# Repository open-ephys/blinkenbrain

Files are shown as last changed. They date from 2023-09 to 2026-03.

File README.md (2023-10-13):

# Blinkenbrain
A mouse brain pendant with chaotic tendencies. It implements a variant of the circuit described in

```
Simple Two-Transistor Single-Supply Resistor–Capacitor Chaotic Oscillator
Lars Keuninckx, Guy Van der Sande, and Jan Danckaert
IEEE TRANSACTIONS ON CIRCUITS AND SYSTEMS—II: EXPRESS BRIEFS, VOL. 62, NO. 9, SEPTEMBER 2015
```

and uses its strange dynamics to blink a blinkenlight.

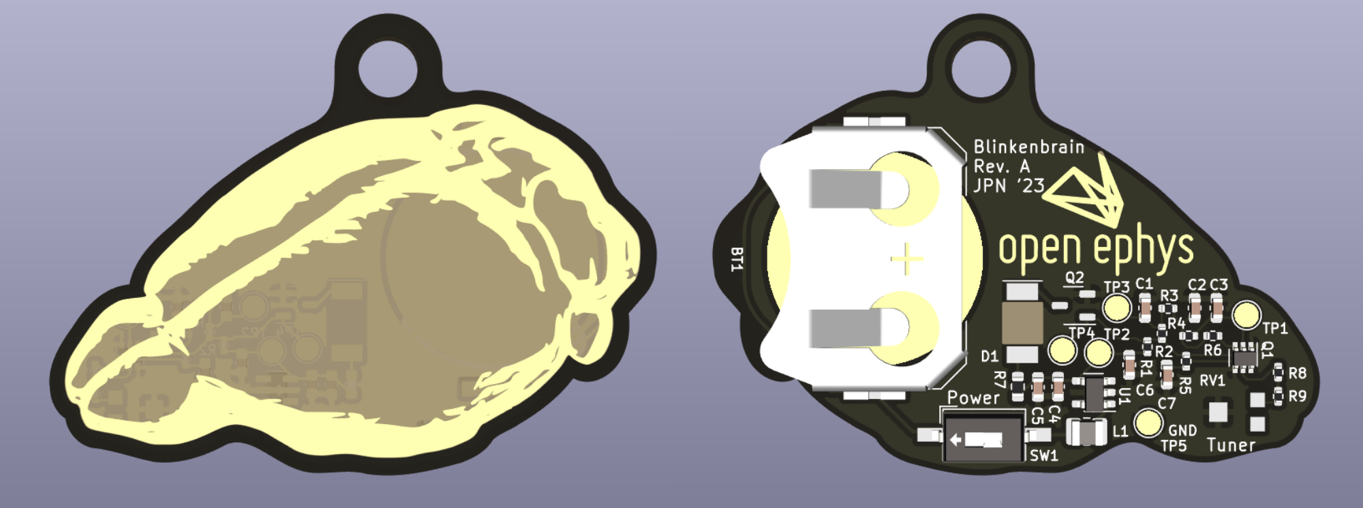
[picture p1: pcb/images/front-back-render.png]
Blinkenbrain rev. A


## How does it blink?

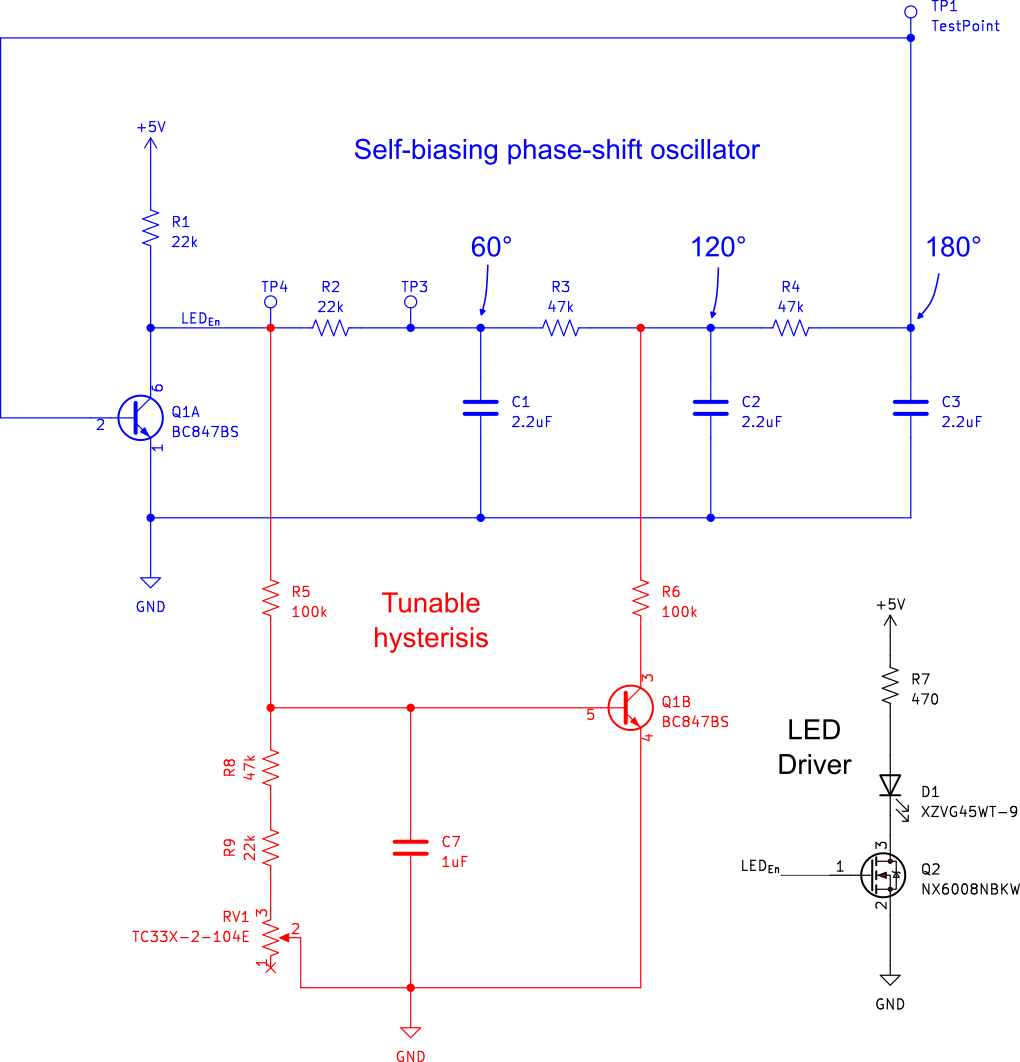
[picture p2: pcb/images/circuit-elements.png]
Chaotic circuit schematic


The circuit consists of a RC phase shift oscillator (blue) combined with what amounts to a tunable Schmitt trigger (red).
The position of the trimpot (RV1) determines if the effect of the Schmitt trigger on the oscillator.

- When the wiper of RV1 is tuned to 0Ω, Q1B does not conduct, and the Schmitt trigger is effectively removed from the circuit
- When the wiper of RV1 is tuned to 100kΩ, Q1B acts as trigger without hysteresis, and therefore conducts in synchrony with the
  RC oscillator.
- When the wiper of RV1 is turned in between these two extremes, a hysteretic path is formed between Q1B's conducting and non-conducting states,
  which results in the emergence of two interacting unstable equilibria and, for some values of RV1, chaotic dynamics.

The gate of an N-channel MOSFET is tied to the collector of Q1A to drive the LED without influencing the
circuit's dynamics. The following image shows V<sub>TP4</sub> vs.V<sub>TP3</sub> when RV1 is tuned to ~70kΩ.

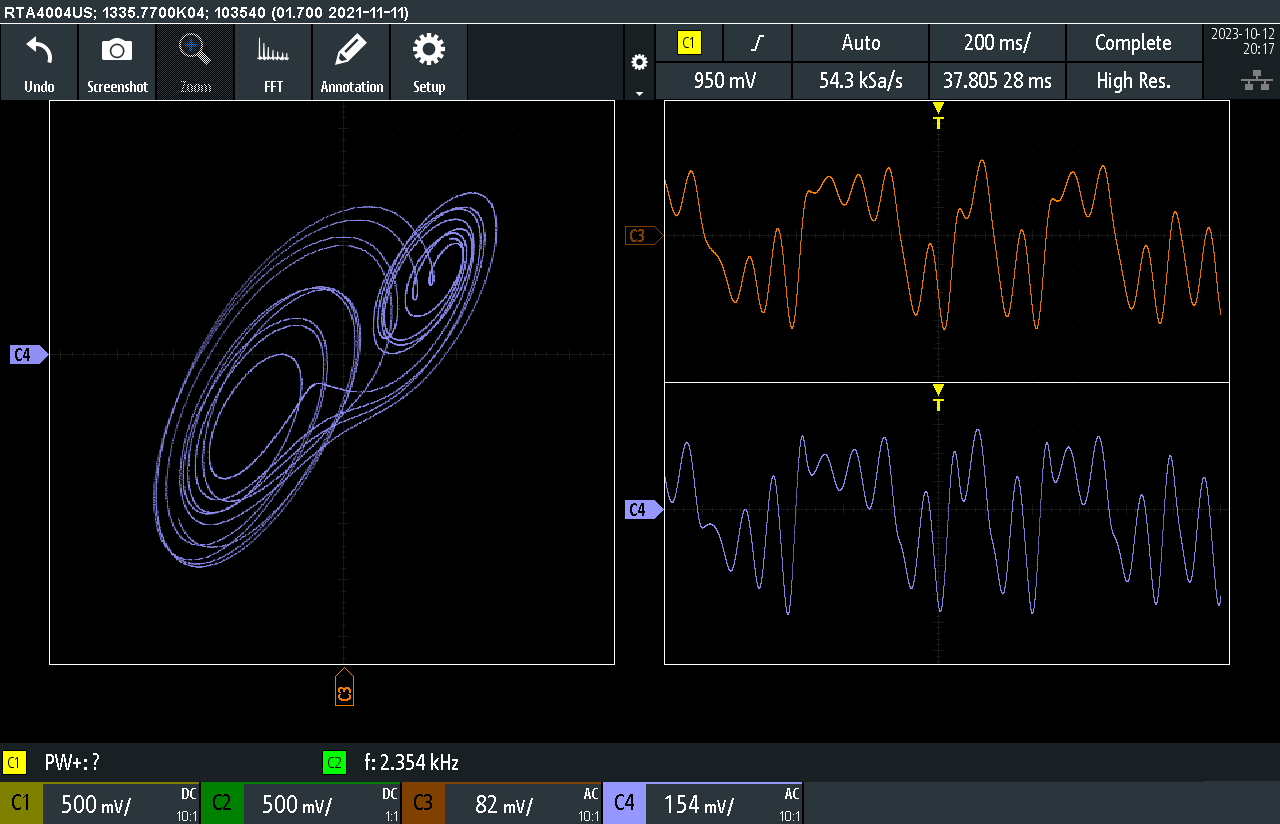
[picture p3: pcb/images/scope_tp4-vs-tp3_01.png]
V(TP4) vs. V(TP3) when RV1 is tuned to ~70kΩ


## License
"No Rights Reserved", CC0

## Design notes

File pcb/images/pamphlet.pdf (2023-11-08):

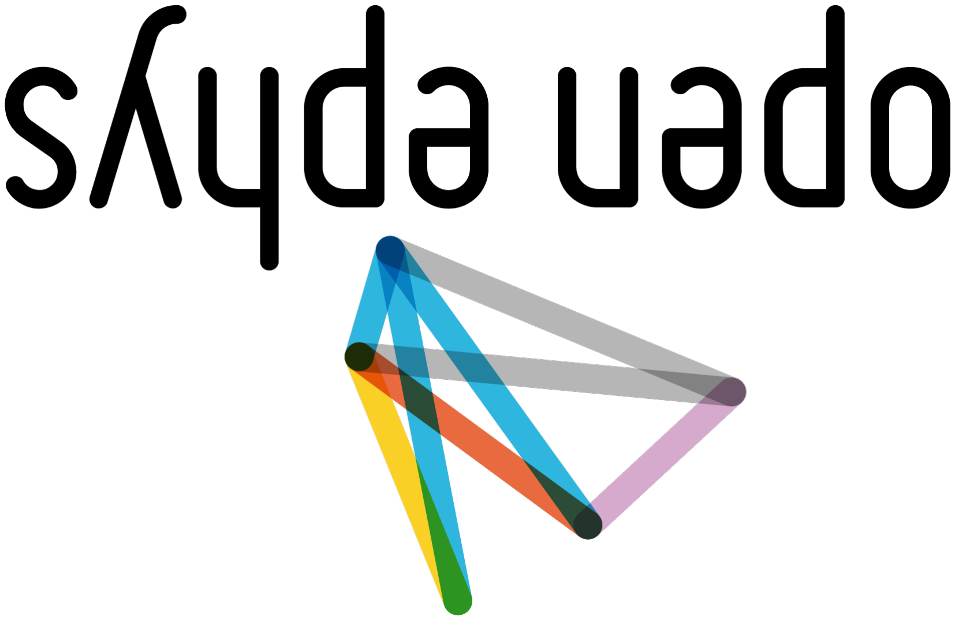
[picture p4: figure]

- When the wiper of RV1 is tuned to 0Ω, Q1B does not conduct, and the Schmitt trigger is effectively removed from the circuit.
- When the wiper of RV1 is tuned to 100kΩ, Q1B acts as trigger without hysteresis, and therefore conducts in synchrony with the RC oscillator.
- When the wiper of RV1 is turned in between these two extremes, a hysteretic path is formed between Q1B's conducting and non-conducting states, which results in the emergence of two interacting unstable equilibria and, for some values of RV1, chaotic dynamics.

The gate of an N-channel MOSFET is tied to the collector of Q1A to drive the LED without influencing the circuit's dynamics. The following image shows VTP4 vs.VTP3 when RV1 is tuned to ~70kΩ.

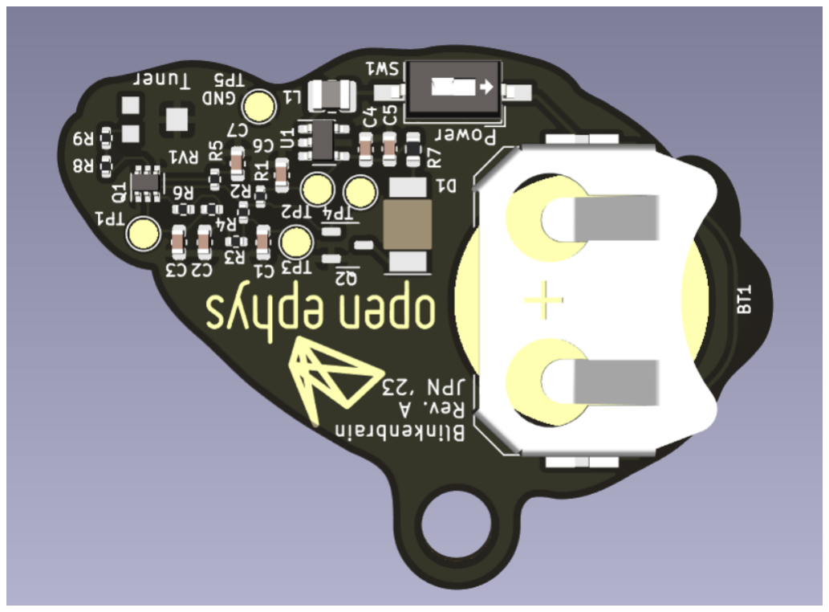
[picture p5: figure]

# How does it blink?

The circuit¹
consists of a RC phase shift oscillator (blue) combined with what amounts to a tunable Schmitt trigger (red). The position of the trimpot (RV1) determines if the effect of the Schmitt trigger on the oscillator.

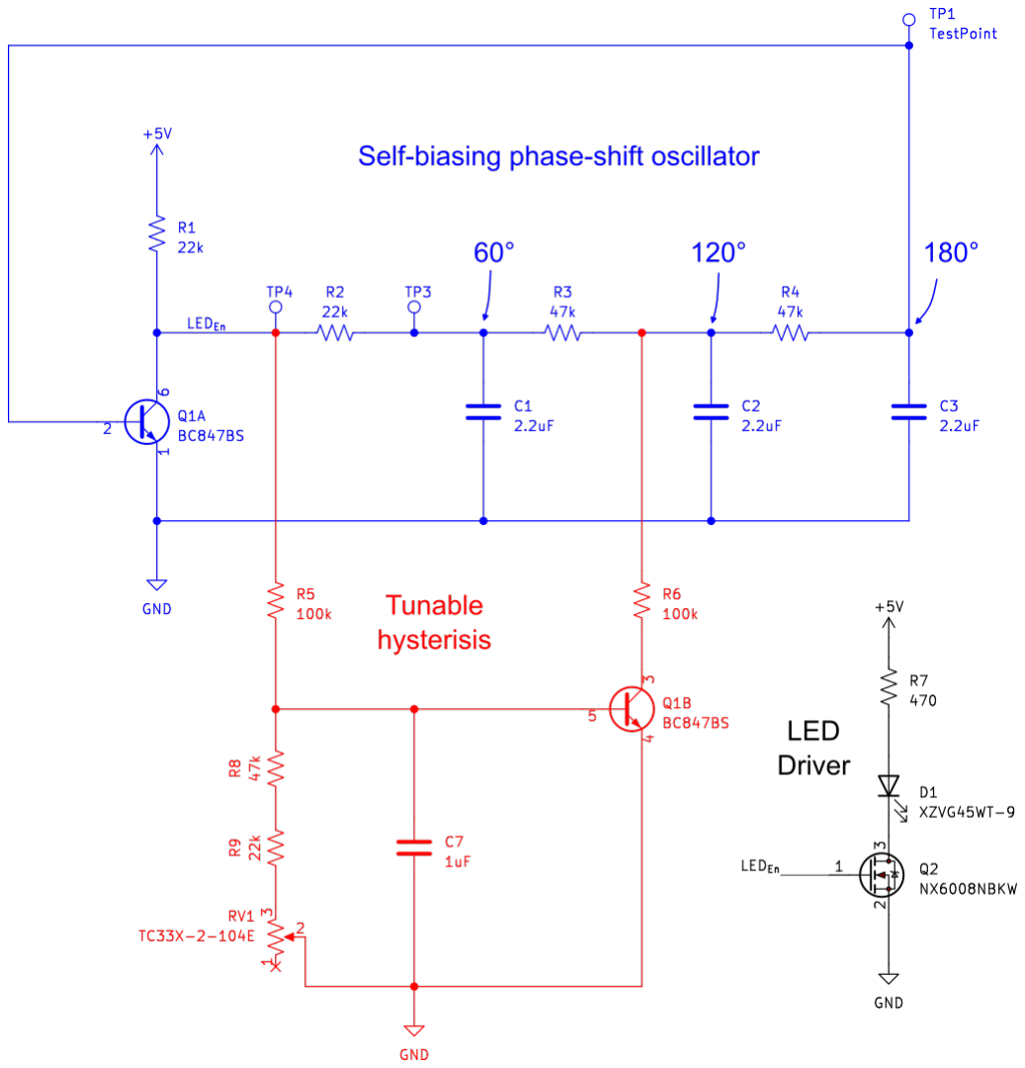
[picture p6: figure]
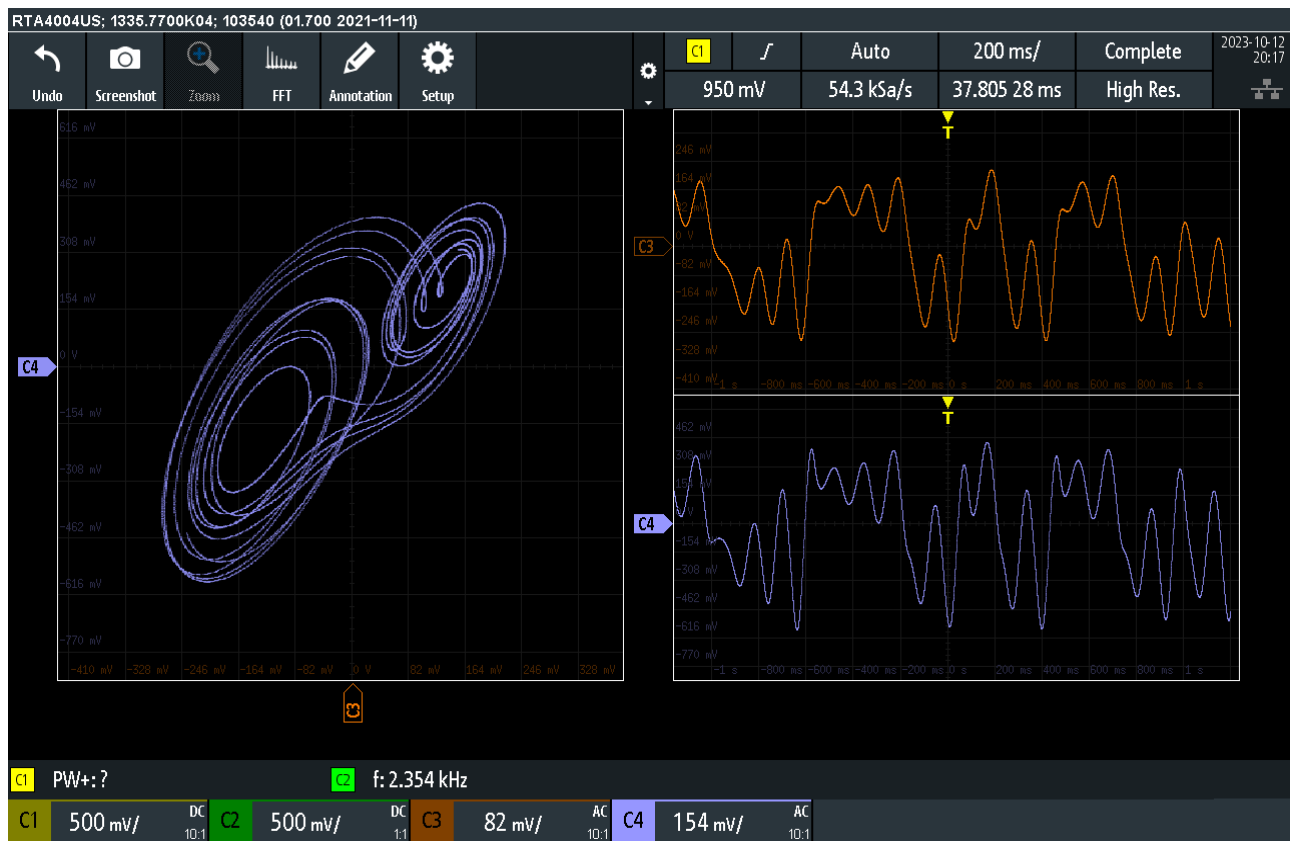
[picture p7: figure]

1. Simple Two-Transistor Single-Supply Resistor–Capacitor Chaotic Oscillator Lars Keuninckx, Guy Van der Sande, and Jan Danckaert IEEE TRANS. ON CIRCUITS AND SYSTEMS II: VOL. 62, NO. 9, 2015

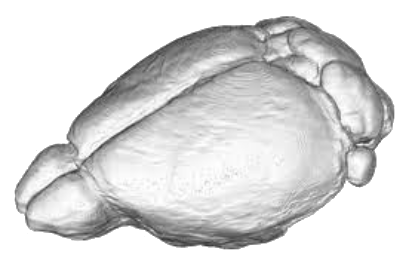
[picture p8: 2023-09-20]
design/brain-image.png

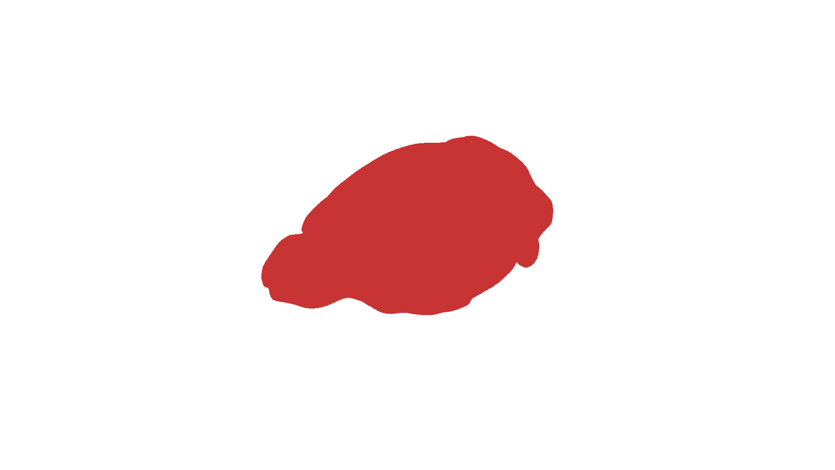
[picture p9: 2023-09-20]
design/brain-mask.png

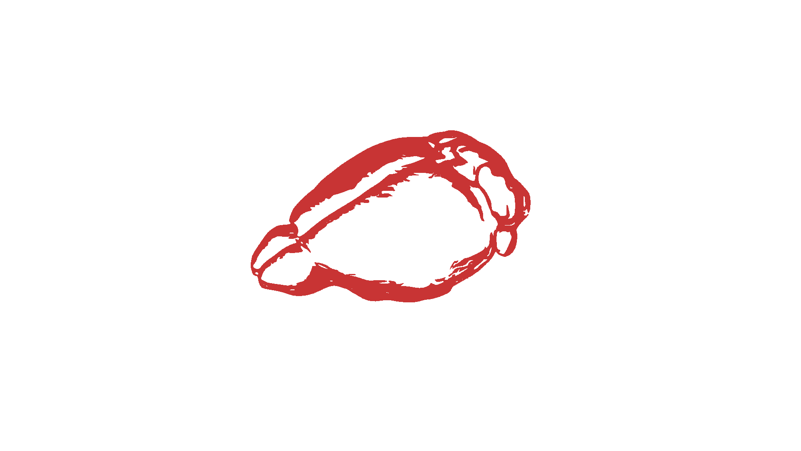
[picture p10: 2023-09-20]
design/brain-copper.png

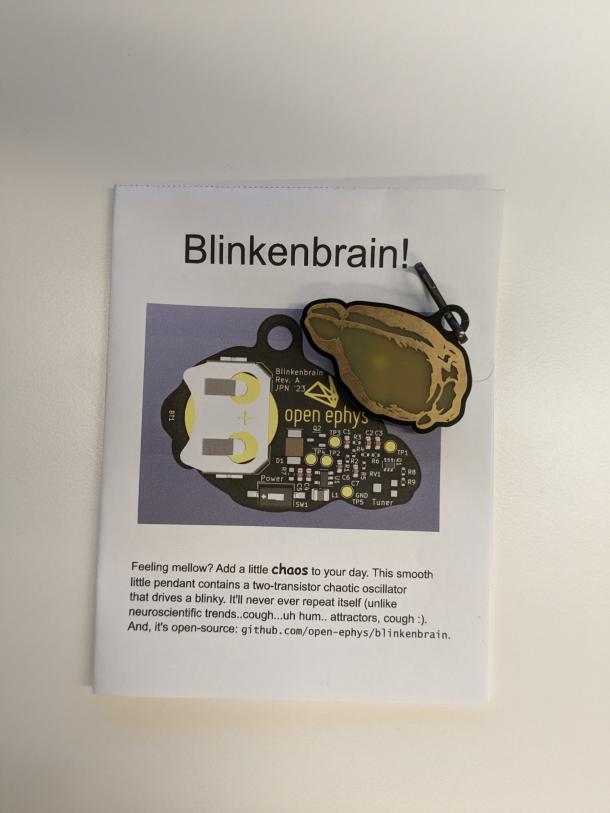
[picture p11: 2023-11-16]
pcb/images/brain-and-datasheet.jpg

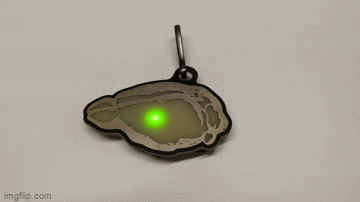
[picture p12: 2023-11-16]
pcb/images/blink.gif

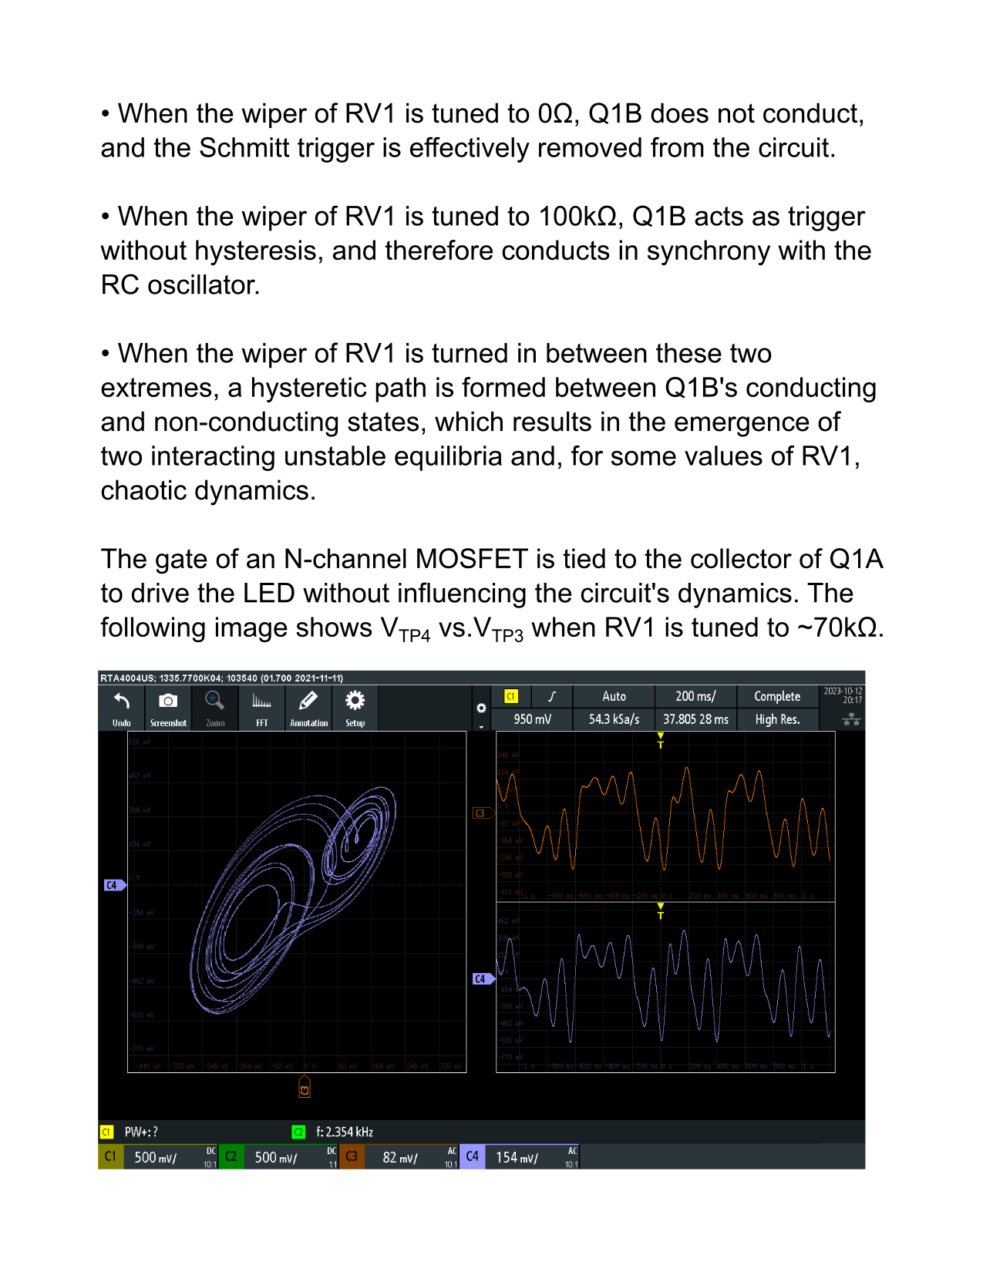
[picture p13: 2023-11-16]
pcb/images/pamphlet-pg3.png

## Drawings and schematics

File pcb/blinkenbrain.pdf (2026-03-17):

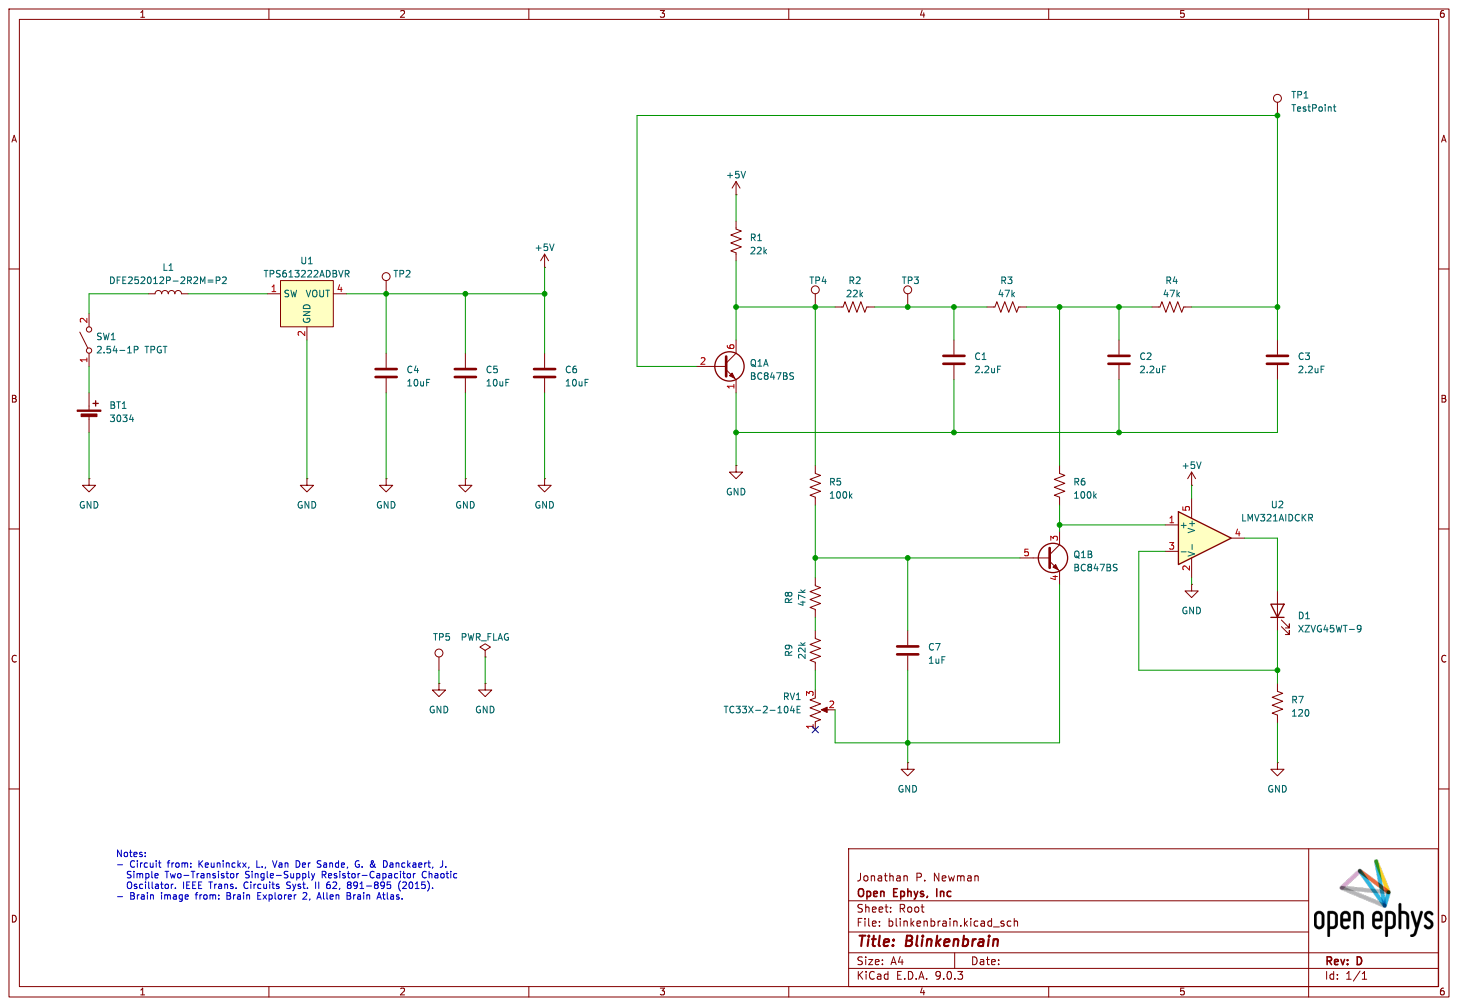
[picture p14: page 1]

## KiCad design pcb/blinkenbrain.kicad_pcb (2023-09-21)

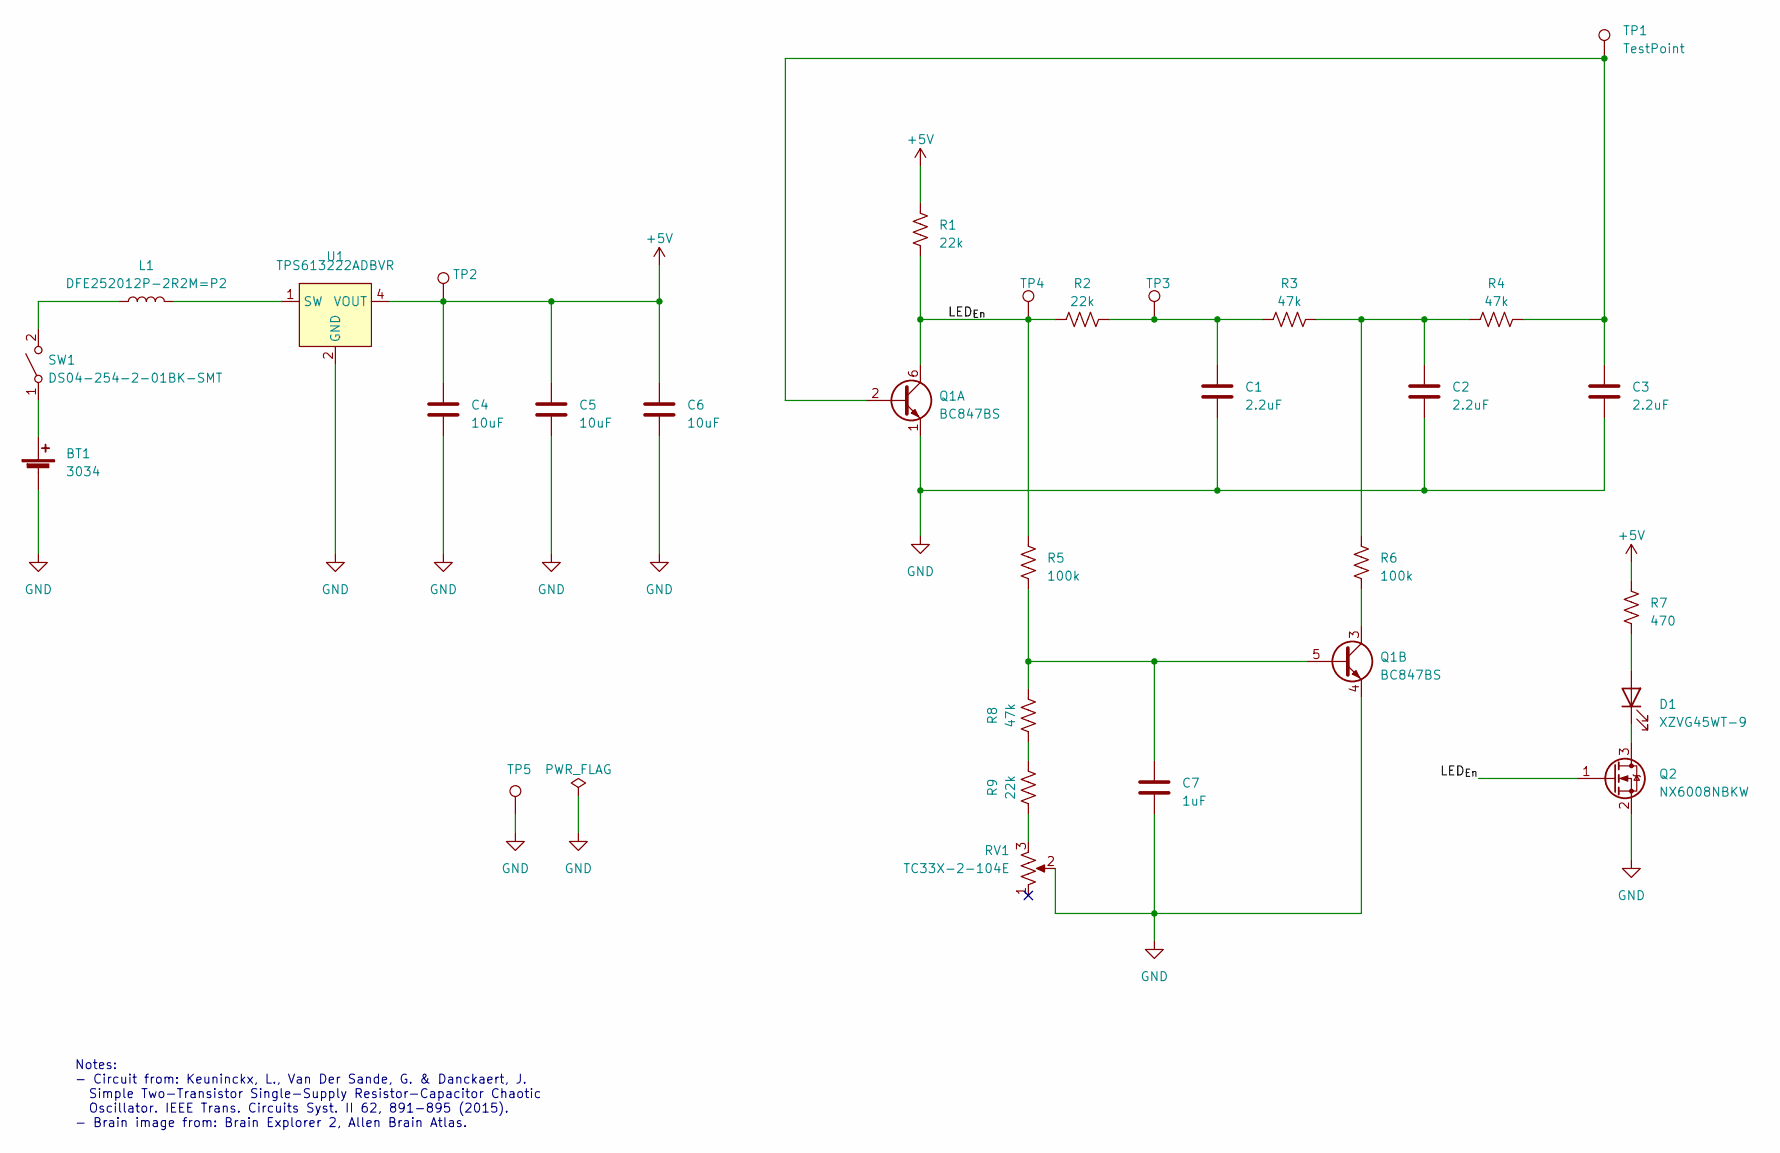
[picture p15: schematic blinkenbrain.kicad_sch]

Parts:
BT1: 3034; BatteryHolder_Keystone_3034_1x20mm
C1, C2, C3: 2.2uF; C_0603_1608Metric; Tolerance 5%; Voltage 10V
C4, C5, C6: 10uF; C_0603_1608Metric; Tolerance 20%; Voltage 16V
C7: 1uF; C_0603_1608Metric; Tolerance 5%; Voltage 10V
D1: XZVG45WT-9; SUNLED_PLCC2-INV
L1: DFE252012P-2R2M=P2; L_1008_2520Metric
Q1: BC847BS; SOT-363_SC-70-6
Q2: NX6008NBKW; SOT-23-3
R1, R2, R9: 22k; R_0402_1005Metric; Tolerance 1%
R3, R4, R8: 47k; R_0402_1005Metric; Tolerance 1%
R5, R6: 100k; R_0402_1005Metric; Tolerance 1%
R7: 470; R_0603_1608Metric; Tolerance 1%
RV1: TC33X-2-104E; BOURNS_TC33
SW1: DS04-254-2-01BK-SMT; SW_DIP_SPSTx01_Slide_6.7x4.1mm_W8.61mm_P2.54mm_LowProfile
TP1, TP2, TP3, TP4, TP5: TestPoint; TestPoint_Pad_D2.0mm
U1: TPS613222ADBVR; SOT-23-5

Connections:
+5V: C4.1, C5.1, C6.1, R1.1, R7.2, TP2.1, U1.4 (VOUT)
/LED_{En}: Q1.6 (C1), Q2.1 (G), R1.2, R2.1, R5.2, TP4.1
GND: BT1.2 (-), C1.2, C2.2, C3.2, C4.2, C5.2, C6.2, C7.2, Q1.1 (E1), Q1.4 (E2), Q2.2 (S), RV1.2, TP5.1, U1.2 (GND)
unnamed: BT1.1 (+), SW1.1 (A)
unnamed: C1.1, R2.2, R3.1, TP3.1
unnamed: C2.1, R3.2, R4.1, R6.2
unnamed: D1.2 (A), R7.1
unnamed: D1.1 (K), Q2.3 (D)
unnamed: C3.1, Q1.2 (B1), R4.2, TP1.1
unnamed: C7.1, Q1.5 (B2), R5.1, R8.2
unnamed: Q1.3 (C2), R6.1
unnamed: R8.1, R9.2
unnamed: R9.1, RV1.3
unnamed: L1.1, SW1.2 (B)
unnamed: L1.2, U1.1 (SW)

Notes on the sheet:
Notes: - Circuit from: Keuninckx, L., Van Der Sande, G. & Danckaert, J. Simple Two-Transistor Single-Supply Resistor-Capacitor Chaotic Oscillator. IEEE Trans. Circuits Syst. II 62, 891-895 (2015). - Brain image from: Brain Explorer 2, Allen Brain Atlas.

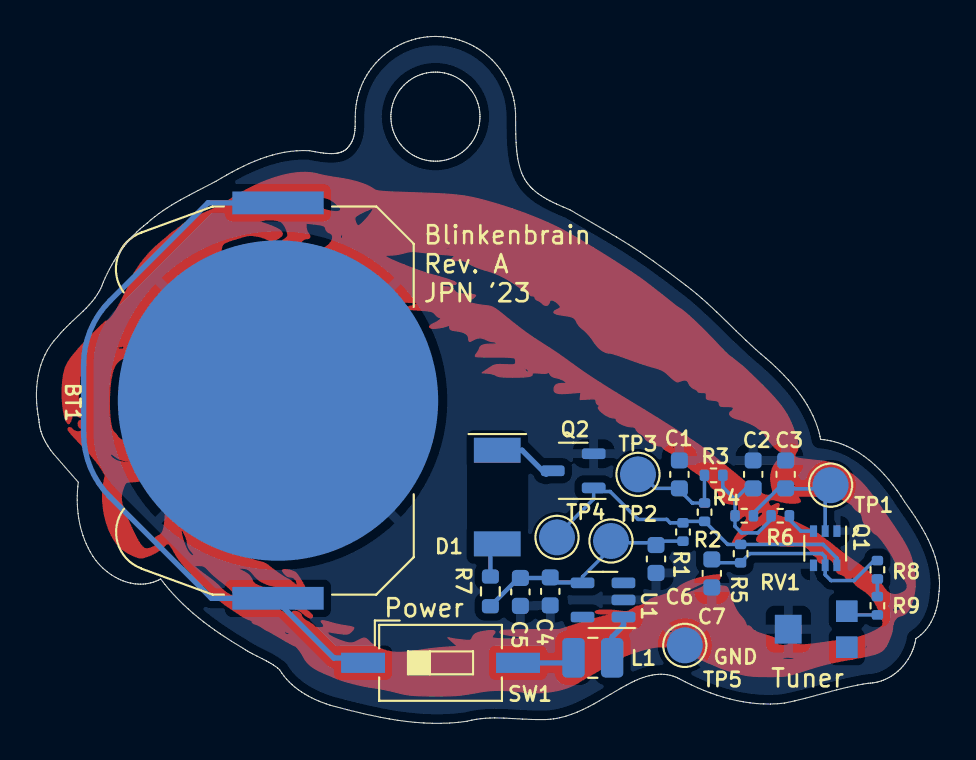
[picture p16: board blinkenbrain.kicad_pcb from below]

Board: 2 copper layers, 50.2 x 38.2 mm, 29 parts (29 on the bottom side), 15 nets.

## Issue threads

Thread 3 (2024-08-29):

Slide switch needs non-flush mechanism

jonnew, 2024-08-29:
Flush slide switch requires screw driver to turn the device on.

jonnew, 2024-10-31:
Fixed in Revision B

Closed 2024-10-31.

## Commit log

2023-09-21 Add more accurate spice models of circuit
    - Use models for the exact part numbers the parts called for on the BOM
2023-09-21 Added assuembly documents for jlcpcb
    [blinkenbrain-B_Cu.gbr, blinkenbrain-B_Fab.gbr, blinkenbrain-B_Mask.gbr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]
2023-10-04 Rev. B
    - Small changes after testing (completely functional but some foot
    prints were a bit off)
    - Changed DIP switch so that its easier to actuate
    - Created 20 peice panel
    [blinkenbrain-bom_PCBWay.xlsx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]
2023-10-12 Improve README
    - Add a description of how the circuit works
2023-10-12 Update README.md
    - Resize schematic
2023-11-16 Add social media post materials.
2024-09-10 Rev. C
    - Fix minor silkscreen errors
    - Remove extra supports from one PCB in center of panel
    [blinkenbrain-pos_pcbway.csv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]
2025-09-23 Initial revision D
    - Parts optimized for JLCPCB production
    - Awaiting on some digikey sourced parts to reach their warehouse. I
    will then use these design files and either merge or update if changes
    are needed.
    [blinkenbrain-B_Cu.gbr, blinkenbrain-B_Fab.gbr, blinkenbrain-B_Mask.gbr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]
2026-03-17 Remove outer mouse bites to aid depanelization
    - The outer mouse bites made it easy for the tabs to stay with the
    brains when they were removed
    - Update spice model to accurately reflect LED current limit resistor.
    [blinkenbrain_panel-B_Cu.gbr, blinkenbrain_panel-B_Fab.gbr, blinkenbrain_panel-B_Mask.gbr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]
